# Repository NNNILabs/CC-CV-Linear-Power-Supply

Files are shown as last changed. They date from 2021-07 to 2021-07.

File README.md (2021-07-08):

# CC CV Linear Power Supply
## Clean and elegant CC CV linear supply, no weird biasing or floating stuff.

I designed this power supply to replace the hacked-together ATX/buck-boost/LT3081 I was using. 
The goal from the beginning was simplicity and to use parts that are easily available, such as those from the JLCPCB parts library.

It is "modular" in the sense that only the op-amps and the associated feedback circuitry were meant to be JLC assmebled, with the MOSFETs, input/output electrolytics, current shunts and protection diodes being added by the user.

Since the parts and topology used are rather straightforward, this thing can even be built on a perfboard (I tried, it worked).

Capabilities:
- Output voltage - 0V to 30V, with "true" 0V (load and MOSFET leakage dependent)
- Output current - 0A to (500mV/Rshunt)A, maximum (limited by parts on the board) 6A per rail, with both MOSFETs populated
- Input voltage - up to 50V

**Important - to make full use of the output voltage and current ranges, the MOSFETs *must* be heatsinked.**

Circuit details:
- 5V for op-amps and reference: 2x 5V regulators to reduce heat dissipation, with an input pre-regulator based on the TL431 so that the 5V regulator's maximum input voltage is not exceeded (in this case 24V) as well as to spread the power dissipation between more parts to reduce temperature rise. Jumper J1 can be shorted if the input voltage is below the maximum rated input voltage for the 5V regulator being used, this reduces input quiescent current.
- Buffered references: The output voltage and current are set using two potentiometers. Since the potentiometers are connected to 5V, the reference voltages for CC and CV are 0V to 5V. The potentiometer outputs are buffered using a dual RRIO op-amp to prevent loading (and therefore errors). This means that the output voltage and current are *independent* of the potentiometer value, but make sure that the current consumed by both potentiometers does not exceed 1mA (or a minimum potentiometer resistance of 5K).
- +CV - straightforward op-amp circuit that compares the CV reference to an output divider
- +CC - a differential amplifier that forms a Howland current source, threshold set by CV reference
- -CV and -CC are not very straightforward - CV forms a "null detector" that tries to maintain 0V at the summing junction of the CV reference and output voltage through appropriately scaled resistors, while the CC differential amplifier sets the summing junction voltage, increasing it if the current limit is reached and therefore reducing output voltage
- MOSFET gate driver - a slightly modified "AB" amplifier to increase the op-amp output current enough to drive the MOSFET gate to higher voltages.

Quirks:
- Minimum -CC threshold is 120mA, for some reason.

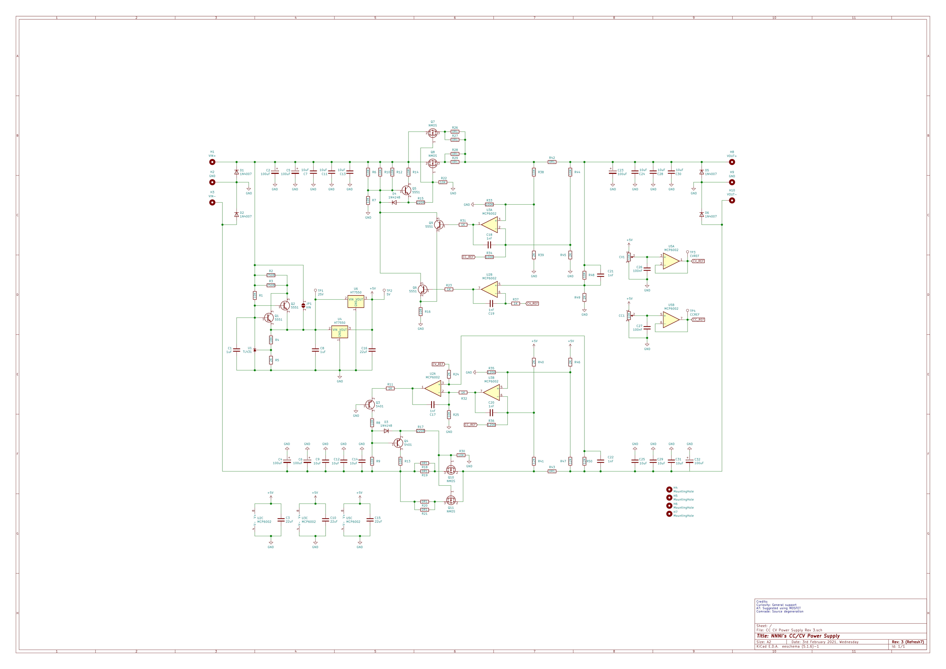
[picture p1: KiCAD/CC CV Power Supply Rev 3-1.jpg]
Schematic


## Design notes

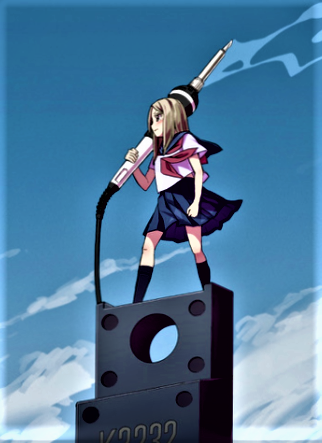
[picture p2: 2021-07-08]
KiCAD/Capture.PNG

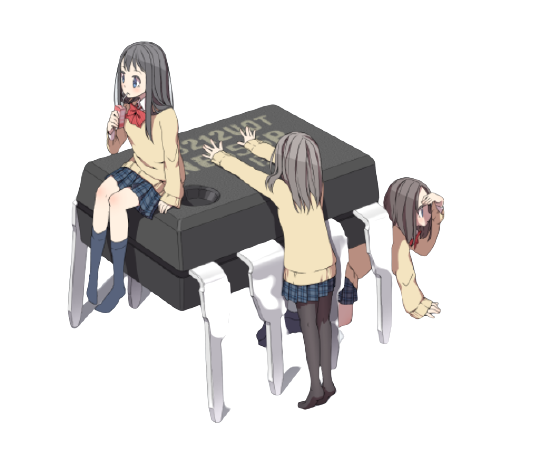
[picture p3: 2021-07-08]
KiCAD/Capture2-removebg-preview.png

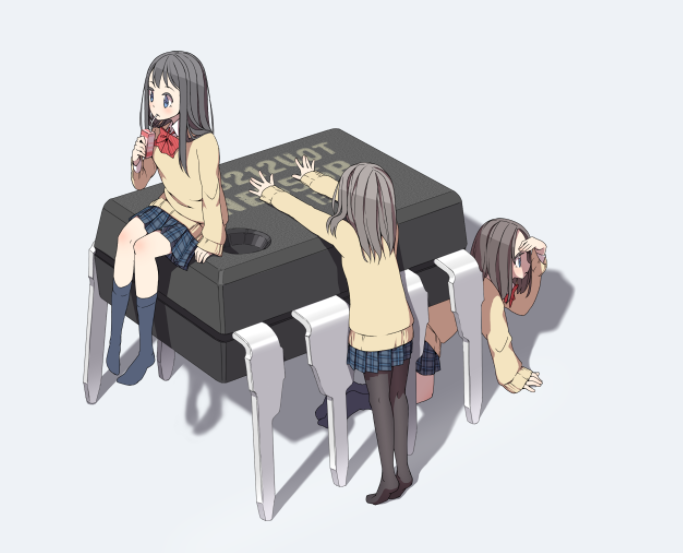
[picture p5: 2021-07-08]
KiCAD/Capture2.PNG

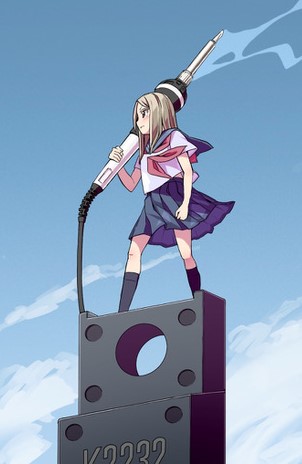
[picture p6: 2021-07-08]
KiCAD/comics_5.jpg

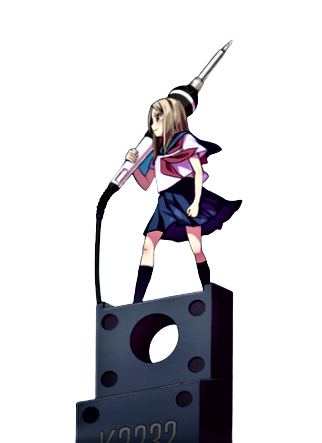
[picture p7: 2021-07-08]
KiCAD/Capture-removebg-preview.png

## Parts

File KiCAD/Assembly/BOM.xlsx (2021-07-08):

Comment | Designator | Footprint | LCSC Part #
22uF Unpolarized capacitor | C1,C2,C3,C11 | C_0603_1608Metric | C59461 (https://lcsc.com/product-detail/Multilayer-Ceramic-Capacitors-MLCC-SMD-SMT_SAMSUNG_CL10A226MQ8NRNC_22uF-226-20-6-3V_C59461.html/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)
100uF Polarized capacitor | C4,C5,C28,C29 | CP_Radial_D8.0mm_P3.50mm
1uF Unpolarized capacitor | C6,C32 | C_0603_1608Metric | C15849 (https://lcsc.com/product-detail/Multilayer-Ceramic-Capacitors-MLCC-SMD-SMT_SAMSUNG_CL10A105KB8NNNC_1uF-105-10-50V_C15849.html/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)
10uF Unpolarized capacitor | C7,C8,C9,C10,C12,C13,C20,C21,C22,C23,C24,C25 | C_1206_3216Metric | C13585 (https://lcsc.com/product-detail/Multilayer-Ceramic-Capacitors-MLCC-SMD-SMT_SAMSUNG_CL31A106KBHNNNE_10uF-106-10-50V_C13585.html/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)
1nF Unpolarized capacitor | C14,C15,C16,C17,C18,C19,C30,C31 | C_0603_1608Metric | C1588 (https://lcsc.com/product-detail/Multilayer-Ceramic-Capacitors-MLCC-SMD-SMT_SAMSUNG_CL10B102KB8NNNC_1nF-102-10-50V_C1588.html/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)
100nF Unpolarized capacitor | C26,C27 | C_0603_1608Metric | C14663 (https://lcsc.com/product-detail/Multilayer-Ceramic-Capacitors-MLCC-SMD-SMT_100nF-104-10-50V_C14663.html/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)
10K Potentiometer | CC1,CV1 | PinHeader_1x03_P2.54mm_Vertical
1N4007 Diode | D1,D2,D3,D4 | D_DO-41_SOD81_P10.16mm_Horizontal
1N4148 Diode | D5,D6 | D_SOD-323 | C2128 (https://lcsc.com/product-detail/Switching-Diode_Changjiang-Electronics-Tech-CJ-1N4148WS_C2128.html/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)
VIN+ Mounting Hole with connection | H1 | MountingHole_2.2mm_M2_DIN965_Pad
GND Mounting Hole with connection | H2,H10 | MountingHole_2.2mm_M2_DIN965_Pad
VIN- Mounting Hole with connection | H4 | MountingHole_2.2mm_M2_DIN965_Pad
MountingHole Mounting Hole without connection | H5,H6,H7,H8 | MountingHole_3.2mm_M3_Pad_Via
VOUT+ Mounting Hole with connection | H9 | MountingHole_2.2mm_M2_DIN965_Pad
VOUT- Mounting Hole with connection | H11 | MountingHole_2.2mm_M2_DIN965_Pad
VIN Solder Jumper, 2-pole, open | JP1 | SolderJumper-2_P1.3mm_Open_RoundedPad1.0x1.5mm
5551 NPN transistor, base/emitter/collector | Q1,Q3,Q8,Q10,Q11 | SOT-23 | C2145 (https://lcsc.com/product-detail/Transistors-NPN-PNP_Changjiang-Electronics-Tech-CJ-MMBT5551_C2145.html/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)
5401 PNP transistor, base/emitter/collector | Q2,Q9 | SOT-23 | C8326 (https://lcsc.com/product-detail/Transistors-NPN-PNP_Changjiang-Electronics-Tech-CJ-MMBT5401_C8326.html/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)
NMOS N-MOSFET transistor, gate/drain/source | Q4,Q5,Q6,Q7 | TO-220-3_Vertical
10K Resistor | R1,R11,R19,R49,R50 | R_0603_1608Metric | C25804 (https://lcsc.com/product-detail/Chip-Resistor-Surface-Mount_Uniroyal-Elec-0603WAF1002T5E_C25804.html/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)
18K Resistor | R2 | R_0603_1608Metric | C25810 (https://lcsc.com/product-detail/Chip-Resistor-Surface-Mount_Uniroyal-Elec-0603WAF1802T5E_C25810.html/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)
2K Resistor | R3,R10,R20,R23,R24,R30,R31 | R_0603_1608Metric | C22975 (https://lcsc.com/product-detail/Chip-Resistor-Surface-Mount_Uniroyal-Elec-0603WAF2001T5E_C22975.html/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)
10K Resistor | R4 | R_0805_2012Metric | C17414 (https://lcsc.com/product-detail/Chip-Resistor-Surface-Mount_Uniroyal-Elec-0805W8F1002T5E_C17414.html/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)
20K Resistor | R5,R29 | R_0805_2012Metric | C4328 (https://lcsc.com/product-detail/Chip-Resistor-Surface-Mount_Uniroyal-Elec-0805W8F2002T5E_C4328.html/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)
1K Resistor | R6,R9,R14,R36,R51 | R_0603_1608Metric | C21190 (https://lcsc.com/product-detail/Chip-Resistor-Surface-Mount_Uniroyal-Elec-0603WAF1001T5E_C21190.html/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)
0R1 Resistor | R7,R8,R12,R13,R37,R38,R39,R40 | R_1206_3216Metric | C25334 (https://lcsc.com/product-detail/Chip-Resistor-Surface-Mount_Uniroyal-Elec-1206W4F100LT5E_C25334.html/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)
100K Resistor | R15,R16 | R_0603_1608Metric | C25803 (https://lcsc.com/product-detail/Chip-Resistor-Surface-Mount_Uniroyal-Elec-0603WAF1003T5E_C25803.html/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)
120K Resistor | R17,R18 | R_0603_1608Metric | C25808 (https://lcsc.com/product-detail/Chip-Resistor-Surface-Mount_Uniroyal-Elec-0603WAF1203T5E_C25808.html/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)
750R Resistor | R21,R28 | R_1206_3216Metric | C17985 (https://lcsc.com/product-detail/Chip-Resistor-Surface-Mount_Uniroyal-Elec-1206W4F7500T5E_C17985.html/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)
10R Resistor | R22,R34,R47,R48 | R_0603_1608Metric | C22859 (https://lcsc.com/product-detail/Chip-Resistor-Surface-Mount_Uniroyal-Elec-0603WAF100JT5E_C22859.html/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)
12K Resistor | R25,R32,R35 | R_0603_1608Metric | C22790 (https://lcsc.com/product-detail/Chip-Resistor-Surface-Mount_Uniroyal-Elec-0603WAF1202T5E_C22790.html/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)
0R1 Resistor | R26,R27 | R_Axial_DIN0614_L14.3mm_D5.7mm_P25.40mm_Horizontal
220R Resistor | R52,R53 | R_0603_1608Metric | C22962 (https://lcsc.com/product-detail/Chip-Resistor-Surface-Mount_Uniroyal-Elec-0603WAF2200T5E_C22962.html/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)
5V test point | TP1 | TestPoint_Pad_D1.0mm
25V test point | TP2 | TestPoint_Pad_D1.0mm
CVREF test point | TP3 | TestPoint_Pad_D1.0mm
CCREF test point | TP4 | TestPoint_Pad_D1.0mm
MCP6002 1MHz, Low-Power Op Amp, SOIC-8 | U1,U2,U4 | SOIC-8_3.9x4.9mm_P1.27mm | C7377 (https://lcsc.com/product-detail/Low-Power-OpAmps_MICROCHIP_MCP6002T-I-SN_MCP6002T-I-SN_C7377.html/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)
TL431 Shunt Regulator, SOT-23 | U3 | SOT-23 | C3113 (https://lcsc.com/product-detail/Voltage-References_Changjiang-Electronics-Tech-CJ-CJ431_C3113.html/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)
HT7550 100mA Low Dropout Voltage Regulator, Fixed Output, SOT89 | U5,U6 | SOT-89-3 | C16106 (https://lcsc.com/product-detail/Low-Dropout-Regulators-LDO_HT7550-1_C16106.html/?href=jlc-SMT)

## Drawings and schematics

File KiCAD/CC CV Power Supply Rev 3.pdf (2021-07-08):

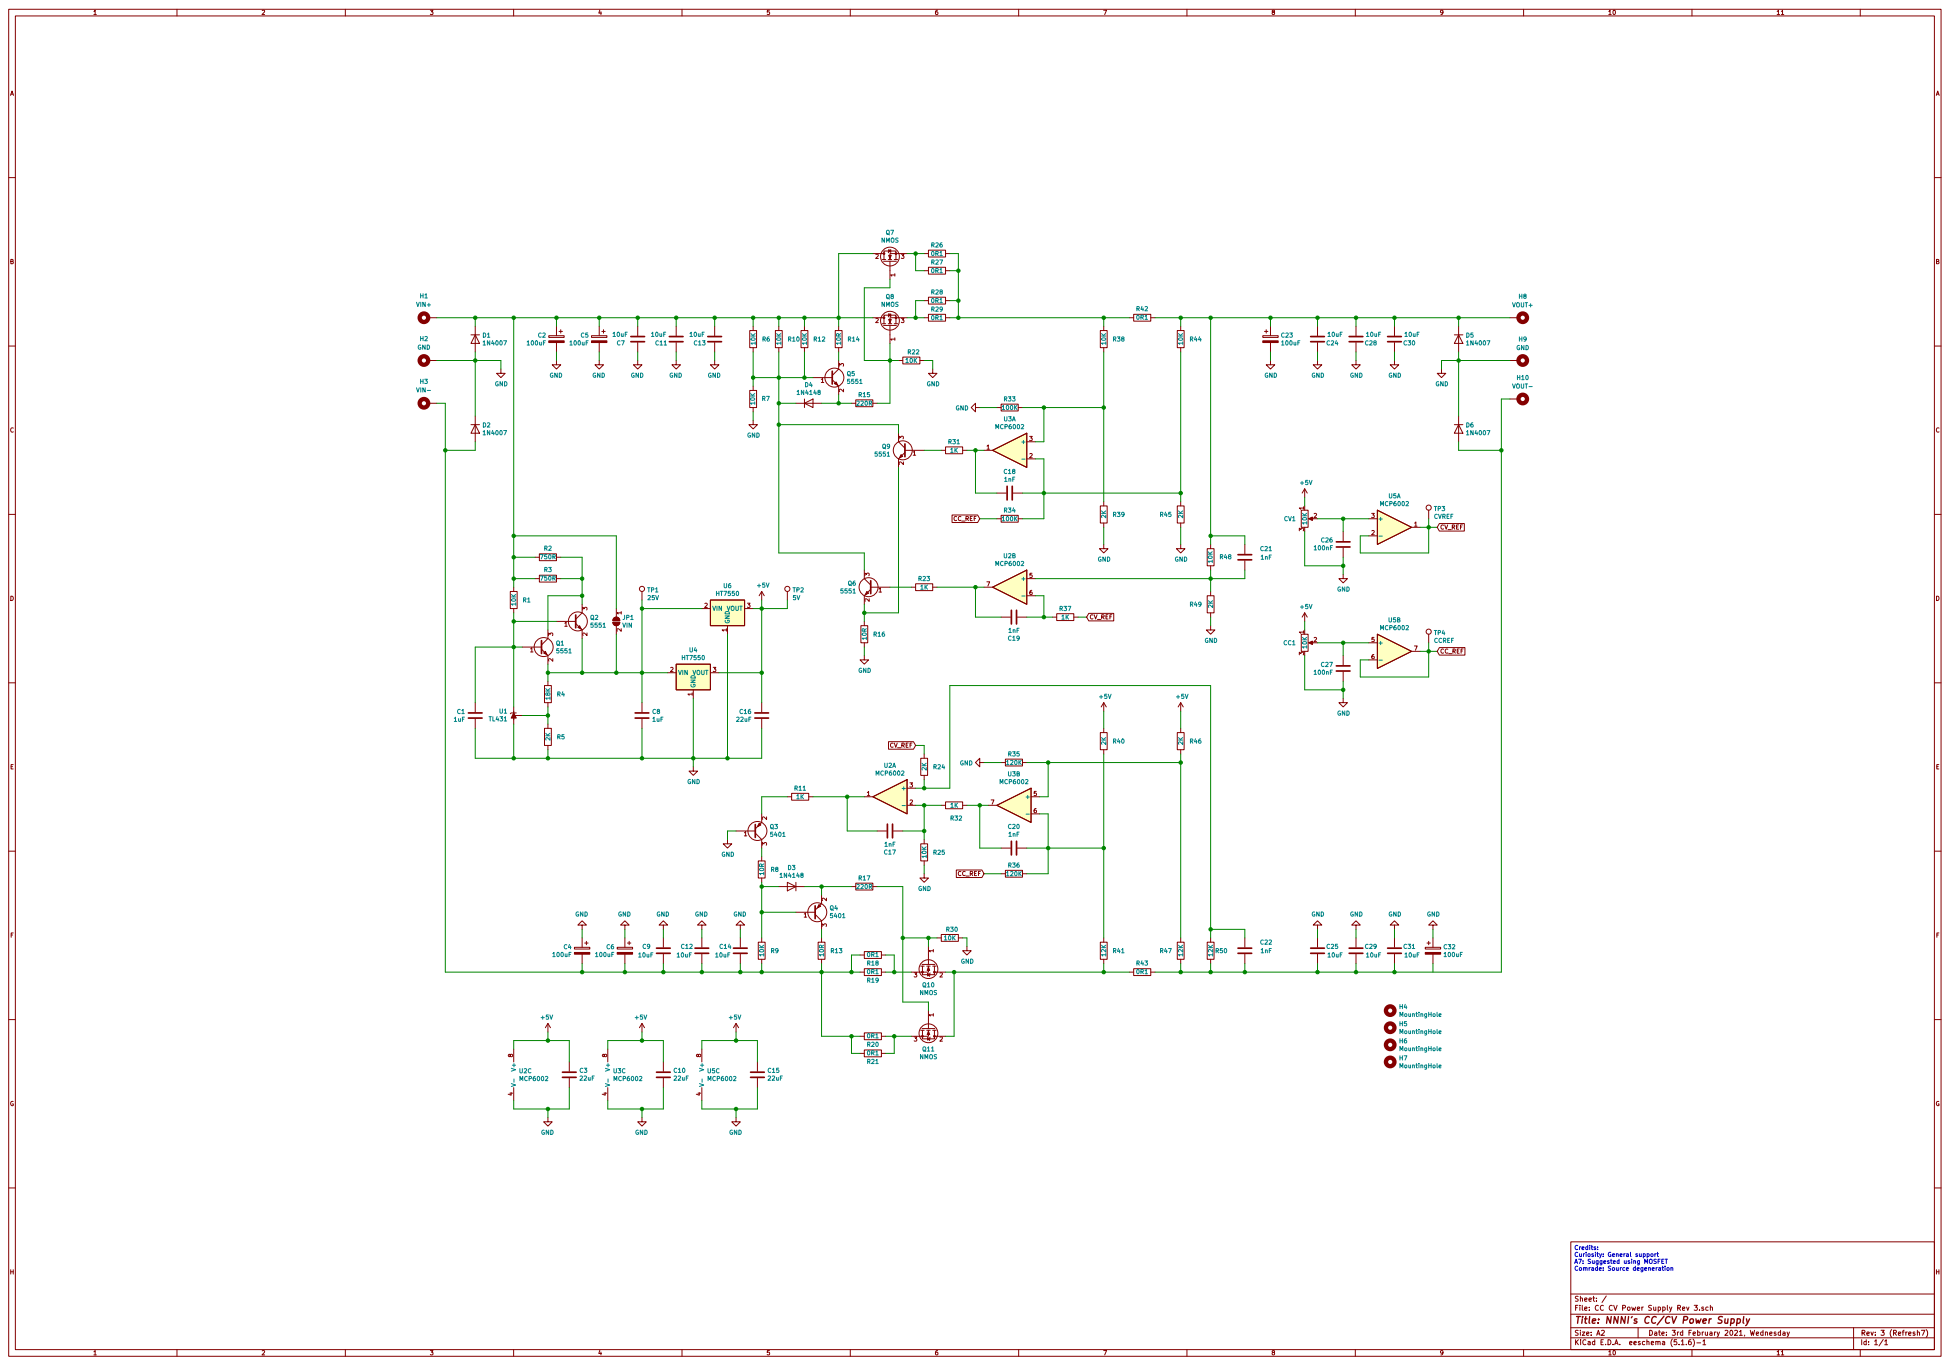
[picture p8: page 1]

Credits: Curiosity: General support

File: CC CV Power Supply Rev 3.sch Sheet: /
Id: 1/1 Title: NNNI's CC/CV Power Supply

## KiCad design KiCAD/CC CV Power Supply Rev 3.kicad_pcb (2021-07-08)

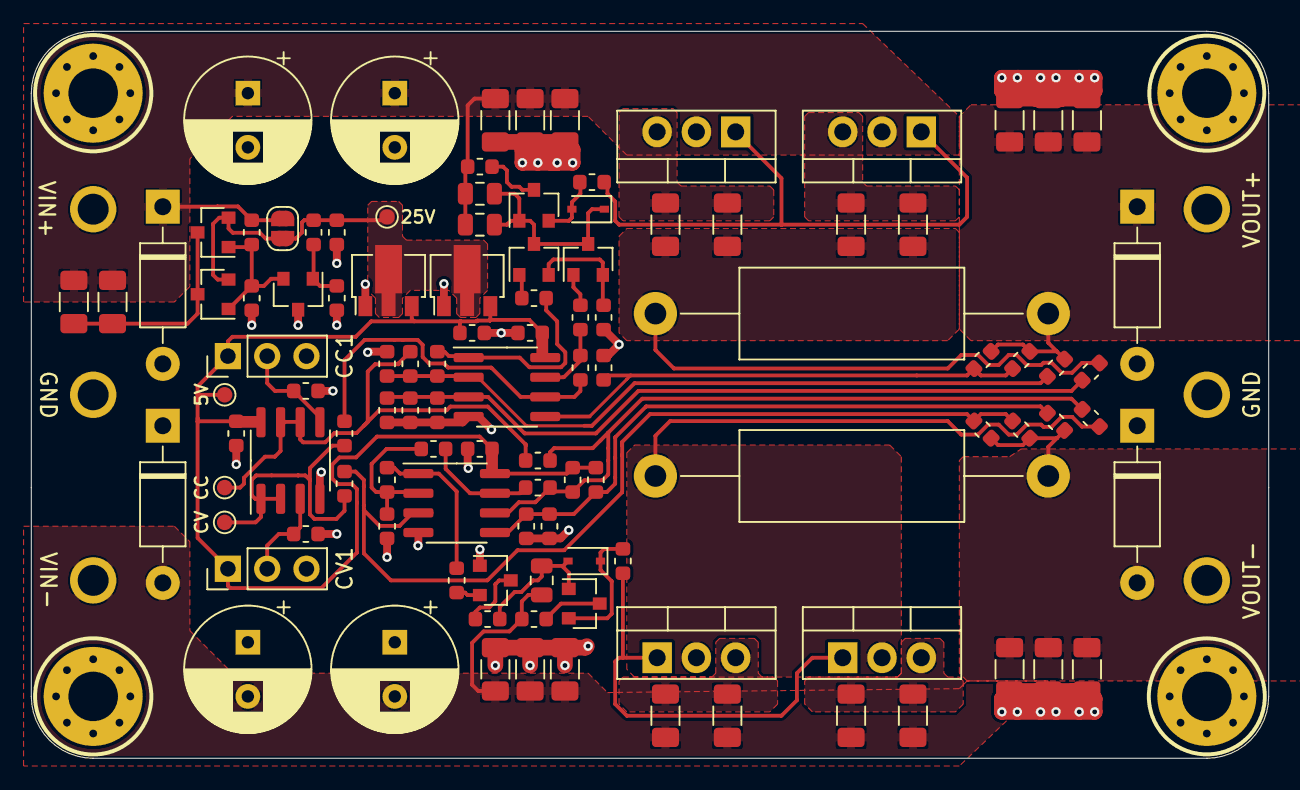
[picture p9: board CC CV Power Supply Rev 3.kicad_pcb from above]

Board: 2 copper layers, 80.0 x 47.0 mm, 118 parts (0 on the bottom side), 45 nets.

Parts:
C1, C2, C3, C11: 22uF; C_0603_1608Metric
C4, C5, C28, C29: 100uF; CP_Radial_D8.0mm_P3.50mm
C6, C32: 1uF; C_0603_1608Metric
C7, C8, C9, C10, C12, C13, C20, C21, C22, C23, C24, C25: 10uF; C_1206_3216Metric
C14, C15, C16, C17, C18, C19, C30, C31: 1nF; C_0603_1608Metric
C26, C27: 100nF; C_0603_1608Metric
CC1: 10K; PinHeader_1x03_P2.54mm_Vertical
CV1: 10K; PinHeader_1x03_P2.54mm_Vertical
D1, D2, D3, D4: 1N4007; D_DO-41_SOD81_P10.16mm_Horizontal
D5, D6: 1N4148; D_SOD-323
H1: VIN+; MountingHole_2.2mm_M2_DIN965_Pad
H2, H10: GND; MountingHole_2.2mm_M2_DIN965_Pad
H4: VIN-; MountingHole_2.2mm_M2_DIN965_Pad
H5, H6, H7, H8: MountingHole; MountingHole_3.2mm_M3_Pad_Via
H9: VOUT+; MountingHole_2.2mm_M2_DIN965_Pad
H11: VOUT-; MountingHole_2.2mm_M2_DIN965_Pad
JP1: VIN; SolderJumper-2_P1.3mm_Open_RoundedPad1.0x1.5mm
Q1, Q3, Q8, Q10, Q11: 5551; SOT-23
Q2, Q9: 5401; SOT-23
Q4, Q5, Q6, Q7: NMOS; TO-220-3_Vertical
R1, R11, R19, R49, R50: 10K; R_0603_1608Metric
R2: 22K; R_0603_1608Metric
R3, R10, R20, R23, R24, R30, R31: 2K; R_0603_1608Metric
R4: 10K; R_0805_2012Metric
R5, R29: 20K; R_0805_2012Metric
R6, R9, R14, R36, R51: 1K; R_0603_1608Metric
R7, R8, R12, R13, R37, R38, R39, R40: 0R1; R_1206_3216Metric
R15, R16: 100K; R_0603_1608Metric
R17, R18: 120K; R_0603_1608Metric
R21, R28: 750R; R_1206_3216Metric
R22, R34, R47, R48: 10R; R_0603_1608Metric
R25, R32, R35: 12K; R_0603_1608Metric
R26, R27: 0R1; R_Axial_DIN0614_L14.3mm_D5.7mm_P25.40mm_Horizontal
R52, R53: 220R; R_0603_1608Metric
TP1: 5V; TestPoint_Pad_D1.0mm
TP2: 30V; TestPoint_Pad_D1.0mm
TP3: CVREF; TestPoint_Pad_D1.0mm
TP4: CCREF; TestPoint_Pad_D1.0mm
U1, U2, U4: MCP6002; SOIC-8_3.9x4.9mm_P1.27mm
U3: TL431; SOT-23
U5, U6: HT7550; SOT-89-3

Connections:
+5V: C1.2, C2.1, C3.2, C11.2, CC1.1, CV1.1, R24.1, R31.1, TP1.1, U1.8, U2.8, U4.8, U5.3, U6.3
CC_REF: R16.2, R18.2, TP4.1, U4.6, U4.7
CV_REF: R10.1, R36.1, TP3.1, U4.1, U4.2
GND: C1.1, C2.2, C3.1, C4.2, C5.1, C6.2, C7.1, C8.1, C9.1, C10.1, C11.1, C12.1, C13.1, C15.2, C18.2, C20.1, C21.1, C22.1, C23.1, C24.1, C25.1, C26.1, C27.2, C28.2, C29.1, C32.2, CC1.3, CV1.3, D1.2, D2.1, D3.2, D4.1, H2.1, H10.1, Q9.1, R3.2, R11.2, R15.2, R17.2, R20.2, R23.2, R30.2, R48.2, U1.4, U2.4, U3.3, U4.4, U5.1, U6.1
unnamed: C6.1, JP1.2, Q1.2, Q11.2, R2.1, TP2.1, U5.2, U6.2
unnamed: C5.2, C8.2, C10.2, C13.2, C29.2, D2.2, H4.1, R4.2, R7.2, R8.2, R34.2, R39.2, R40.2
unnamed: C4.1, C7.2, C9.2, C12.2, C28.1, D1.1, H1.1, JP1.1, Q6.2, Q7.2, R1.1, R5.1, R21.2, R28.2, R29.1, R47.1
unnamed: C14.1, R6.1, U2.1
unnamed: C14.2, R11.1, R51.2, U2.2
unnamed: C15.1, R15.1, R23.1, R49.2, U1.3
unnamed: C16.1, R14.1, U1.1
unnamed: C16.2, R16.1, R30.1, R50.2, U1.2
unnamed: C17.1, R9.1, U1.7
unnamed: C17.2, R36.2, U1.6
unnamed: C18.1, R17.1, R31.2, R32.1, U2.5
unnamed: C19.1, R51.1, U2.7
unnamed: C19.2, R18.1, R24.2, R25.1, U2.6
unnamed: C20.2, C22.2, C24.2, C30.1, D3.1, H9.1, R19.2, R26.2, R50.1
unnamed: C21.2, C23.2, C25.2, C31.2, D4.2, H11.1, R27.2, R32.2, R35.2
unnamed: C26.2, CV1.2, U4.3
unnamed: C27.1, CC1.2, U4.5
unnamed: C30.2, R19.1, R20.1, U1.5
unnamed: C31.1, R10.2, R35.1, U2.3
unnamed: C32.1, Q1.1, Q11.1, R1.2, U3.1
unnamed: D5.1, Q2.2, R53.2
unnamed: D5.2, Q2.1, R4.1, R22.2
unnamed: D6.1, Q3.3, Q8.3, Q10.1, R5.2, R29.2
unnamed: D6.2, Q10.2, R52.2
unnamed: Q1.3, Q11.3, R21.1, R28.1
unnamed: Q2.3, R34.1
unnamed: Q3.1, R9.2
unnamed: Q3.2, Q8.2, R48.1
unnamed: Q4.1, Q5.1, R53.1
unnamed: Q4.2, Q5.2, R25.2, R27.1
unnamed: Q4.3, R7.1, R39.1
unnamed: Q5.3, R8.1, R40.1
unnamed: Q6.1, Q7.1, R52.1
unnamed: Q6.3, R12.2, R37.2
unnamed: Q7.3, R13.2, R38.2
unnamed: Q8.1, R14.2
unnamed: Q9.2, R6.2
unnamed: Q9.3, R22.1
unnamed: Q10.3, R47.2
unnamed: R2.2, R3.1, U3.2
unnamed: R12.1, R13.1, R26.1, R37.1, R38.1, R49.1
